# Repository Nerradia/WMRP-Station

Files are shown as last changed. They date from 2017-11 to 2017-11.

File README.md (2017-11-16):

# WMRP-Station

Seeing the quality of WMRP tips from Weller, I wanted to buil my own station, cheaper that the official one.
It is still in development and some improvements are still to be made.
There is two PCBs : The first one seats in the base, and the other one is in the handle.

The first circuit has two microcontrollers, one dedicated to power regulation, and the other one for everything else. The power regulation is made with a half-bridge filtered with two LC low-pass filters. The PWM frequency is at about 100 KHz (I'm not sure, I need to check that), this way, the heating element will receive a smooth current and voltage. On an early version of this station, which was sending square-waves, it seemed to break the heating element.

The second is just made of some sensors to measure temperature of the tip, measure the acceleration of the handle (for automatic start and stop), to detect touch and finally to light up an RGB LED. These two last functions are not yet implemented, I neeed to make an other PCB.

To order the last version of PCBs :
https://pcbs.io/share/zjX5Z
https://pcbs.io/share/z5bD1

BOM is coming soon.

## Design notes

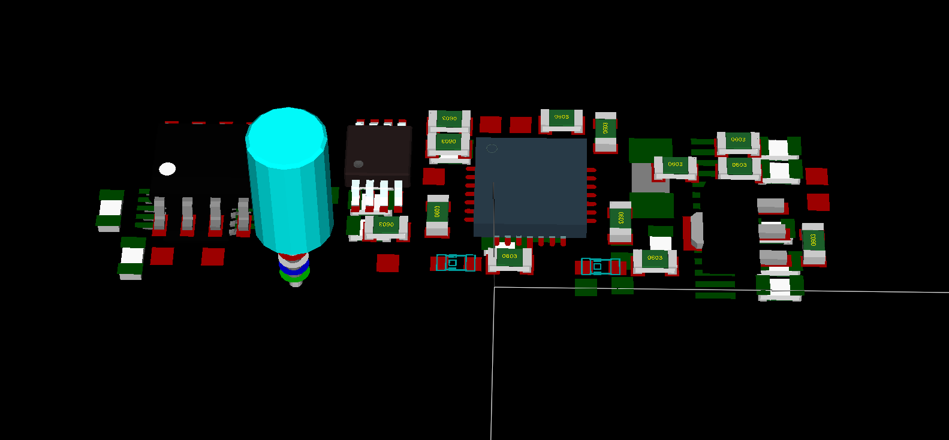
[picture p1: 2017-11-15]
handle/fer_a_souder.png

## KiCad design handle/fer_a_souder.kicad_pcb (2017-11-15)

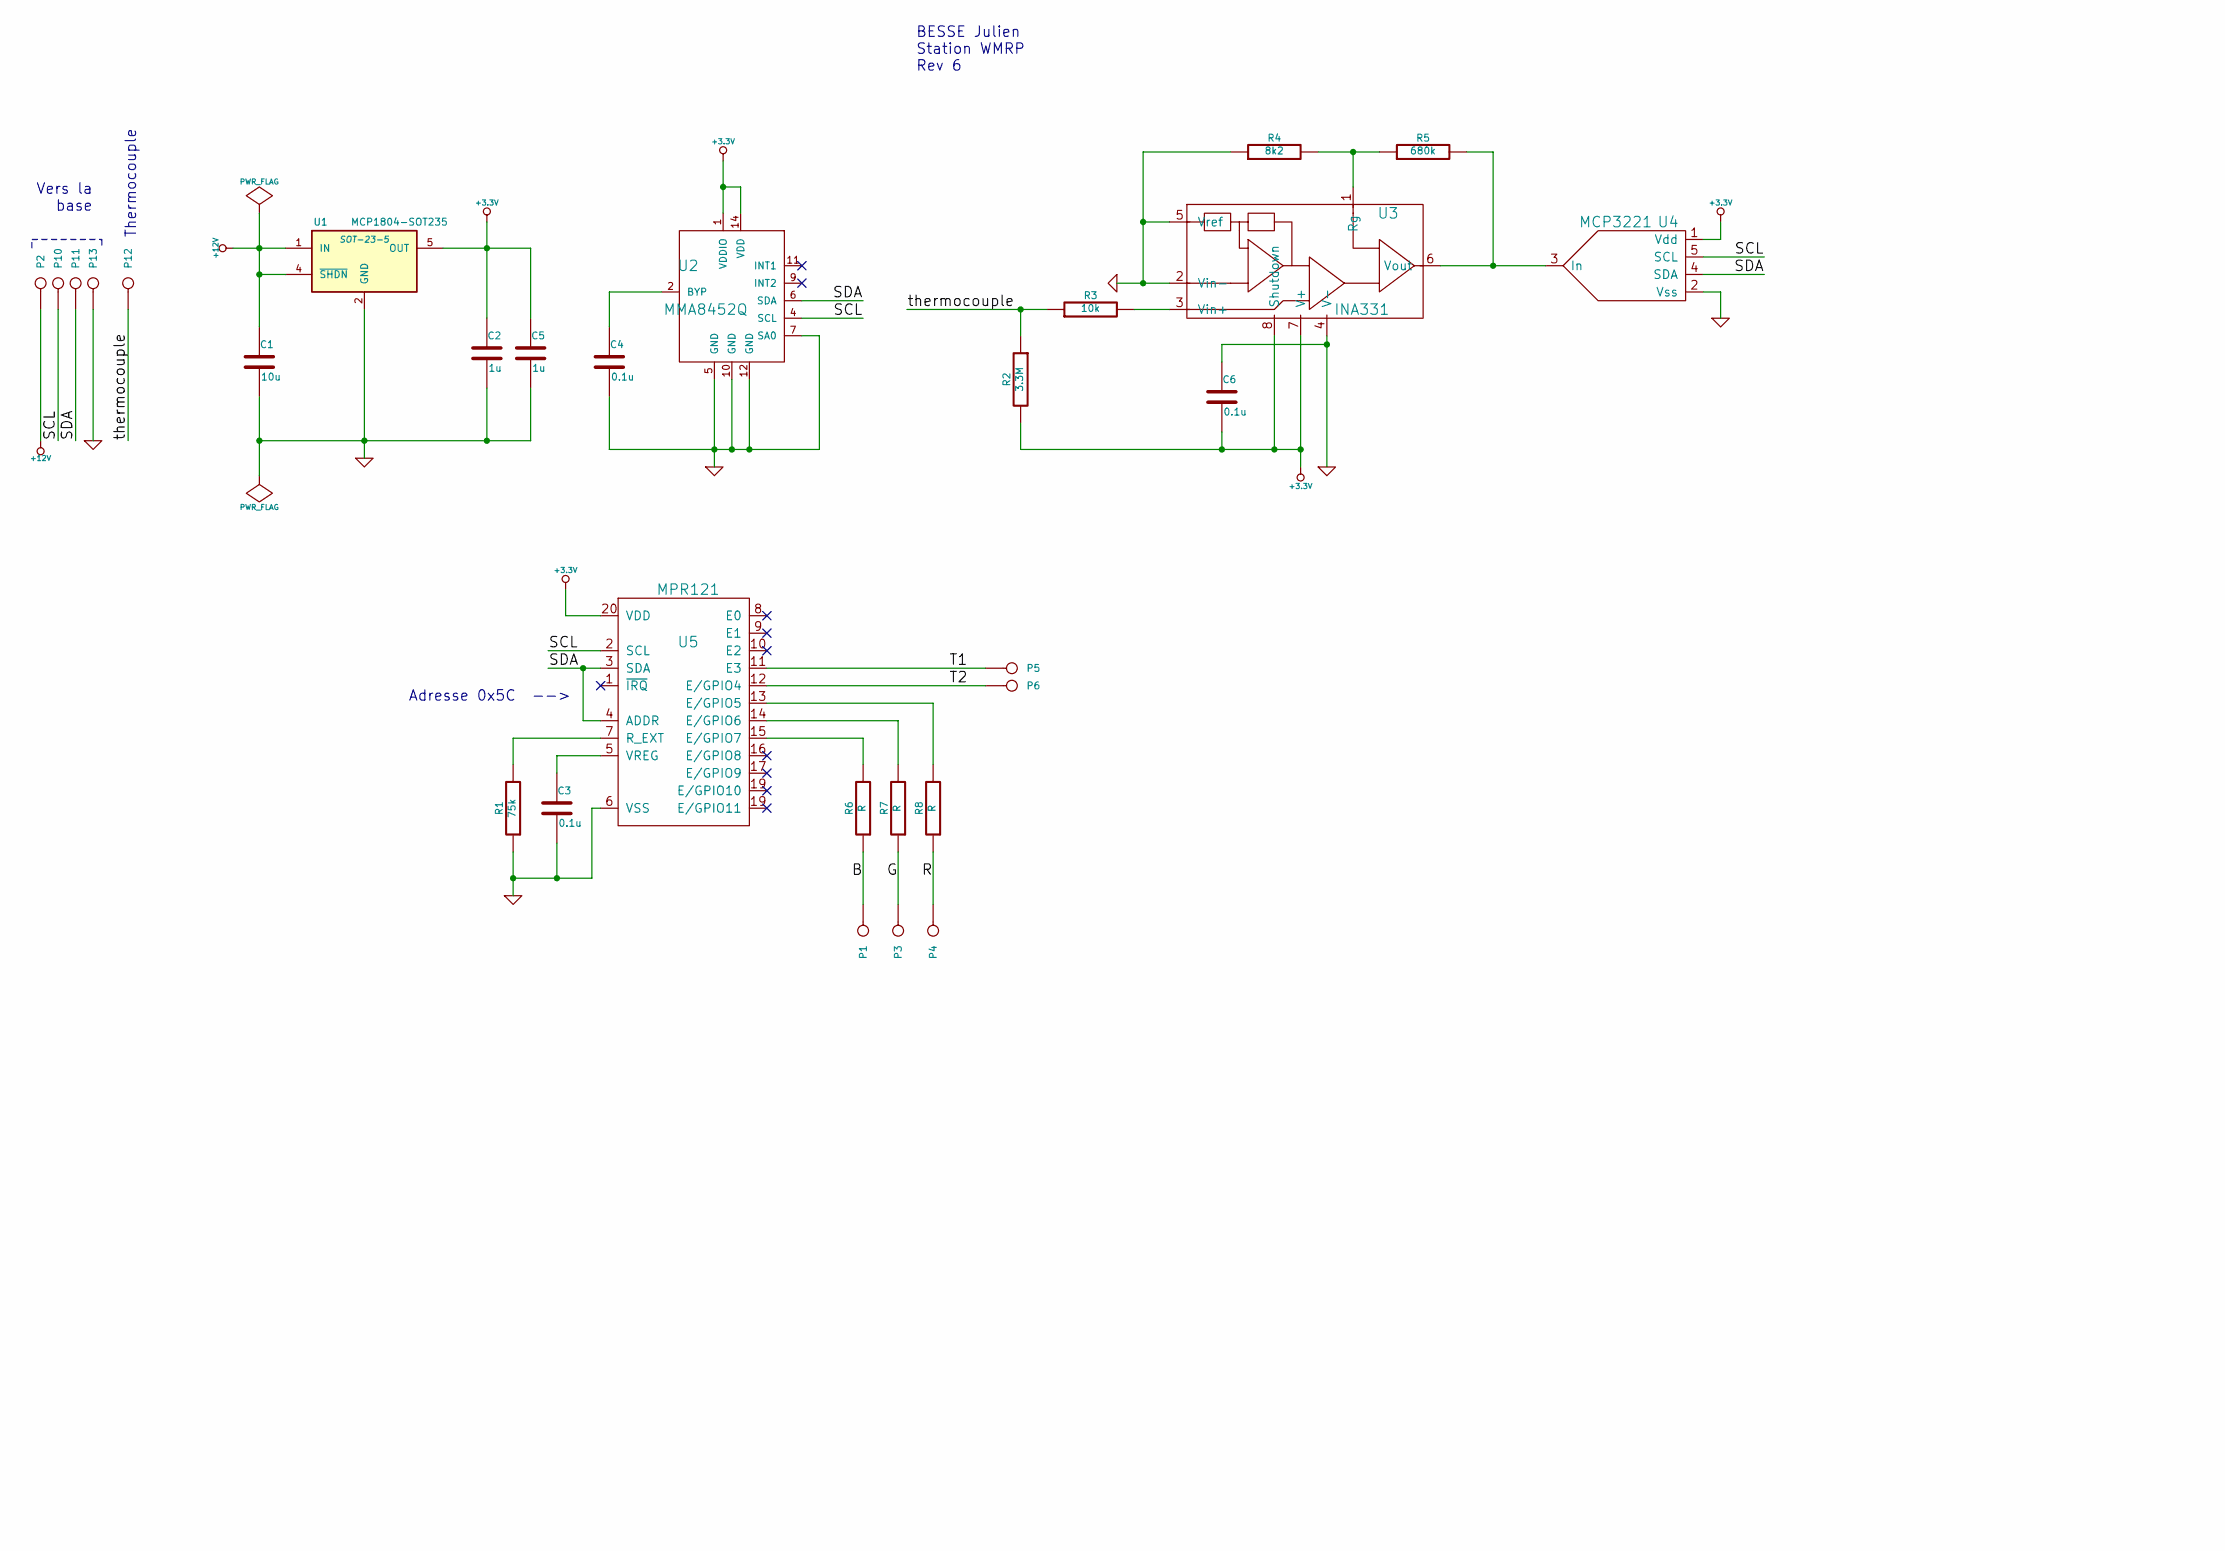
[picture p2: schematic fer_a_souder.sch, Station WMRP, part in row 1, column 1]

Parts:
C1: 10u
C2, C5: 1u
C3, C4, C6: 0.1u
P1, P2, P3, P4, P5, P6, P10, P11, P12, P13: CONN_1
R1: 75k
R2: 3.3M
R3: 10k
R4: 8k2
R5: 680k
R6, R7, R8: R
U1: MCP1804-SOT235; SOT-23-5
U2: MMA8452Q
U3: INA331
U4: MCP3221
U5: MPR121

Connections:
+3.3V: C2.1, C5.1, C6.2, R2.2, U1.5 (OUT), U2.1 (VDDIO), U2.14 (VDD), U3.7 (V+), U3.8 (Shutdown), U4.1 (Vdd), U5.20 (VDD)
+12V: C1.1, P2.1, U1.1 (IN), U1.4 (~SHDN)
/B: P1.1, R6.1
/G: P3.1, R7.1
/R: P4.1, R8.1
/SCL: P10.1, U2.4 (SCL), U4.5 (SCL), U5.2 (SCL)
/SDA: P11.1, U2.6 (SDA), U4.4 (SDA), U5.3 (SDA), U5.4 (ADDR)
/T1: P5.1, U5.11 (E3)
/T2: P6.1, U5.12 (E/GPIO4)
/thermocouple: P12.1, R2.1, R3.1
GND: C1.2, C2.2, C3.2, C4.2, C5.2, C6.1, P13.1, R1.1, R4.1, U1.2 (GND), U2.5 (GND), U2.7 (SA0), U2.10 (GND), U2.12 (GND), U3.2 (Vin-), U3.4 (V-), U3.5 (Vref), U4.2 (Vss), U5.6 (VSS)
unnamed: R1.2, U5.7 (R_EXT)
unnamed: C3.1, U5.5 (VREG)
unnamed: R8.2, U5.13 (E/GPIO5)
unnamed: R7.2, U5.14 (E/GPIO6)
unnamed: R6.2, U5.15 (E/GPIO7)
unnamed: C4.1, U2.2 (BYP)
unnamed: R4.2, R5.1, U3.1 (Rg)
unnamed: R3.2, U3.3 (Vin+)
unnamed: R5.2, U3.6 (Vout), U4.3 (In)

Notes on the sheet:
BESSE Julien Station WMRP Rev 6
Vers la base
Thermocouple
Adresse 0x5C -->

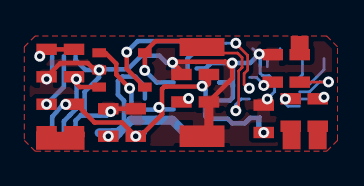
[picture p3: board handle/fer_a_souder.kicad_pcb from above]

Board: 2 copper layers, 29 parts (0 on the bottom side), 20 nets.

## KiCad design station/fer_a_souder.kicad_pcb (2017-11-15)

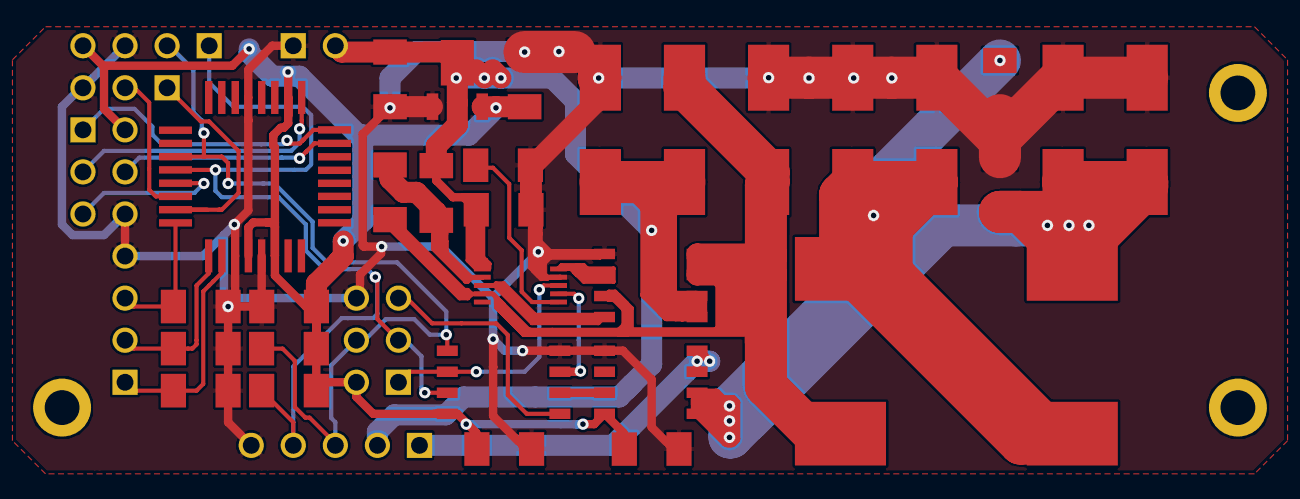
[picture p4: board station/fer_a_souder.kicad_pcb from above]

Board: 2 copper layers, 42 parts (0 on the bottom side), 26 nets.

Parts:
C1, C2, C3, C6, C7, C12, C15, C17: 1u; SM1206
C4: CAPAPOL; SMD2917
C5, C8, C16, C18: 100u; SMD2917
C10, C13, C14: 1n; SM1206
C11: 200n; SM1206
CON1, CON2: AVR-ISP-6; pin_array_3x2
D1, D2: DIODESCH; SMD2917
D5: DIODE; SM1206
IC1: ATMEGA328P-A; TQFP32
IC2: ATTINY85-S; SOIC-8
K1: CONN_3; PIN_ARRAY_3X1
L1, L2: 47u; INDCMS12.5
P1: CONN_2; PIN_ARRAY_2X1
P2: CONN_5; PIN_ARRAY_5x1
P3, P4: CONN_4; PIN_ARRAY_4x1
R1: 10k; SM1206
R2, R3: 2.2k; SM1206
TrouFixation2.1mm, TrouFixation2.1mm#2, TrouFixation2.1mm#3: P***; trouFixation3.1mm
U1: 7805; sot89
U2: LM5106; msoic-10
U3: ACS712; so-8
U5: FDS6898A; so-8
svg2mod-rev: G***; svg2mod-rev

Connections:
+3.3V: C1.1, C3.1, C6.2, C7.1, CON1.2, CON2.2, IC1.4, IC1.6, IC1.18, IC2.8, P3.4, R2.1, R3.1, U1.VO, U3.8
+12V: C2.1, C4.1, C12.1, D1.1, D5.1, P1.2, P2.2, U1.VI, U2.1, U5.5, U5.6
/ISENS: IC2.2, U3.7
/MISO: CON1.1, IC1.16
/MISO2: CON2.1, IC2.6, U2.8
/MOSI: CON1.4, IC1.15
/MOSI2: CON2.4, IC1.27, IC2.5, P2.3, P3.2, R2.2
/RST: CON1.5, IC1.29
/RST_2: CON2.5, IC2.1
/RXD: IC1.30, K1.2
/SCK: CON1.3, IC1.17
/SCK_2: CON2.3, IC1.28, IC2.7, P2.4, P3.1, R3.2
/TXD: IC1.31, K1.1
/p: C10.1, IC1.2, P4.1
/pont_en: IC2.3, U2.7
/r+: C14.1, IC1.32, P4.3
/r-: C13.1, IC1.1, P4.2
/resistance: P2.1, U3.3, U3.4
GND: C1.2, C2.2, C3.2, C4.2, C5.2, C6.1, C7.2, C8.2, C10.2, C12.2, C13.2, C14.2, C15.2, C16.2, C17.2, C18.2, CON1.6, CON2.6, D2.2, IC1.3, IC1.5, IC1.21, IC2.4, K1.3, P1.1, P2.5, P3.3, P4.4, R1.2, U1.GND, U2.9, U3.5, U5.1
unnamed: C11.1, D5.2, U2.2
unnamed: R1.1, U2.6
unnamed: U2.3, U5.4
unnamed: U2.10, U5.2
unnamed: C11.2, D1.2, D2.1, L1.1, U2.4, U5.3, U5.7, U5.8
unnamed: C8.1, C17.1, C18.1, L2.2, U3.1, U3.2
unnamed: C5.1, C15.1, C16.1, L1.2, L2.1

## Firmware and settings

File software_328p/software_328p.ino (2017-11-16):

/* ************************
	Julien BESSE
	https://julienbesse.fr

	First sketch for the soldering station.

	Compile it for "Arduino breadboard 8 MHz" :
		Go to https://www.arduino.cc/en/Tutorial/ArduinoToBreadboard,
		Then read "Minimal Circuit"

	Upload it to the microcontroller with an ISP programmer

This software is VERY UGLY as I just made a sketch to test the hardware. I need to clean it and use english instead of french.

*/

/*********************************************************************
This example is for a 128x64 size display using I2C to communicate
3 pins are required to interface (2 I2C and one reset)

Adafruit invests time and resources providing this open source code, 
please support Adafruit and open-source hardware by purchasing 
products from Adafruit!

Written by Limor Fried/Ladyada  for Adafruit Industries.  
BSD license, check license.txt for more information
All text above, and the splash screen must be included in any redistribution
*********************************************************************/
#include <EEPROM.h>
#include <SPI.h>
#include <Wire.h>
#include <Adafruit_GFX.h>
#include <Adafruit_SSD1306.h>
#include <SparkFun_MMA8452Q.h>
#include <Adafruit_MLX90614.h>
#include "Adafruit_MPR121.h"
#include <avr/wdt.h>

#define OLED_RESET 7
Adafruit_SSD1306 display(OLED_RESET);

#define NUMFLAKES 10
#define XPOS 0
#define YPOS 1
#define DELTAY 2

#define pin_n 3
#define pin_p 2
#define pin_bp 4

MMA8452Q accel;
Adafruit_MLX90614 mlx = Adafruit_MLX90614();

Adafruit_MPR121 cap = Adafruit_MPR121();

uint16_t TemperatureCible = 300;
uint16_t acc;
uint8_t capteurIR = 0; // Booléen indiquant la présence d'un capteur GY-906
uint8_t MPR = 0; // Pareil pour capteur tacile et LED

#define LOGO_H 49 
#define LOGO_W  72
const unsigned char logo [] PROGMEM = {
  // 'g4798'
  0x00, 0x00, 0x00, 0x00, 0x00, 0x00, 0x00, 0x00, 0x00, 0x00, 0x00, 0x00, 0x00, 0x00, 0x00, 0x00, 
  0x00, 0x06, 0x00, 0x00, 0x00, 0x00, 0x00, 0x00, 0x00, 0x00, 0x1c, 0x00, 0x00, 0x00, 0x00, 0x00, 
  0x00, 0x00, 0x00, 0x38, 0x00, 0x00, 0x00, 0x00, 0x00, 0x00, 0x00, 0x00, 0xf0, 0x00, 0x00, 0x00, 
  0x00, 0x00, 0x00, 0x00, 0x03, 0xe0, 0x00, 0x00, 0x00, 0x00, 0x00, 0x00, 0x00, 0x07, 0xc0, 0x00, 
  0x00, 0x00, 0x00, 0x00, 0x00, 0x00, 0x1f, 0x00, 0x00, 0x00, 0x00, 0x00, 0x00, 0x00, 0x00, 0x7e, 
  0x00, 0x00, 0x00, 0x00, 0x00, 0x00, 0x00, 0x00, 0xfc, 0x00, 0x00, 0x00, 0x00, 0x00, 0x00, 0x00, 
  0x13, 0xf0, 0x00, 0x00, 0x00, 0x00, 0x00, 0x00, 0x00, 0x6f, 0xe0, 0x00, 0x00, 0x00, 0x00, 0x00, 
  0x00, 0x00, 0xdf, 0x80, 0x00, 0x00, 0x00, 0x00, 0x00, 0x00, 0x03, 0xff, 0x00, 0x00, 0x00, 0x00, 
  0x00, 0x00, 0x00, 0x07, 0xfc, 0x00, 0x00, 0x00, 0x00, 0x00, 0x00, 0x00, 0x1f, 0xf8, 0x00, 0x06, 
  0x00, 0x00, 0x00, 0x00, 0x40, 0x3f, 0xe0, 0x00, 0x3c, 0x00, 0x00, 0x00, 0x00, 0x40, 0x7f, 0xc0, 
  0x00, 0xf8, 0x00, 0x00, 0x00, 0x00, 0xc1, 0xff, 0x00, 0x07, 0xe0, 0x00, 0x00, 0x00, 0x01, 0x83, 
  0xfe, 0x00, 0x1f, 0xc0, 0x00, 0x00, 0x00, 0x03, 0x9f, 0xf8, 0x00, 0xff, 0x00, 0x00, 0x00, 0x00, 
  0x03, 0x3f, 0xf0, 0x37, 0xf8, 0x00, 0x1f, 0xf0, 0x7f, 0xff, 0xff, 0xc3, 0xff, 0xe0, 0x00, 0x1f, 
  0xf0, 0x7f, 0xff, 0xff, 0x9f, 0xff, 0x80, 0x00, 0x1f, 0xf0, 0x7f, 0xff, 0xfe, 0xff, 0xfc, 0x00, 
  0x00, 0x01, 0xf0, 0x7c, 0x3f, 0xff, 0xff, 0xe0, 0x00, 0x00, 0x01, 0xf0, 0x7c, 0x1f, 0xff, 0xff, 
  0x00, 0x00, 0x00, 0x01, 0xf0, 0x7c, 0x1f, 0xff, 0xfc, 0x00, 0x00, 0x00, 0x01, 0xf0, 0x7c, 0x1f, 
  0xff, 0xe0, 0x00, 0x00, 0x1c, 0x01, 0xf0, 0x7f, 0xff, 0xff, 0x00, 0x00, 0x1f, 0xf8, 0x01, 0xf0, 
  0x7f, 0xff, 0xf0, 0xff, 0xbf, 0xff, 0xc0, 0x01, 0xf0, 0x7f, 0xff, 0xff, 0xff, 0xff, 0xfc, 0x00, 
  0x01, 0xf0, 0x7f, 0xff, 0xff, 0xff, 0xff, 0xc0, 0x00, 0x01, 0xf0, 0x7c, 0x0f, 0xff, 0xff, 0xf0, 
  0x00, 0x00, 0x01, 0xf0, 0x7c, 0x07, 0xff, 0xfc, 0x00, 0x00, 0x00, 0x01, 0xf0, 0x7c, 0x07, 0xfc, 
  0x00, 0x00, 0x00, 0x00, 0x01, 0xf0, 0x7c, 0x0f, 0xff, 0x80, 0x00, 0x00, 0x00, 0x83, 0xf0, 0x7c, 
  0x1f, 0xff, 0xfc, 0x00, 0x00, 0x00, 0xff, 0xf0, 0x7f, 0xff, 0xff, 0xfe, 0x00, 0x00, 0x00, 0xff, 
  0xe0, 0x7f, 0xff, 0xff, 0xff, 0xff, 0x00, 0x00, 0xff, 0xc0, 0x7f, 0xff, 0xc7, 0xff, 0xff, 0xfe, 
  0x00, 0x7f, 0x00, 0x00, 0x1f, 0xf8, 0x01, 0xff, 0xfe, 0x00, 0x00, 0x00, 0x00, 0x03, 0xfe, 0x00, 
  0x00, 0x00, 0x00, 0x00, 0x00, 0x00, 0x00, 0xff, 0x80, 0x00, 0x00, 0x00, 0x00, 0x00, 0x00, 0x00, 
  0x1f, 0xe0, 0x00, 0x00, 0x00, 0x00, 0x00, 0x00, 0x00, 0x03, 0xf0, 0x00, 0x00, 0x00, 0x00, 0x00, 
  0x00, 0x00, 0x00, 0x7e, 0x00, 0x00, 0x00, 0x00, 0x00, 0x00, 0x00, 0x00, 0x07, 0xc0, 0x00, 0x00, 
  0x00, 0x00, 0x00, 0x00, 0x00, 0x00, 0x70, 0x00, 0x00
};

#if (SSD1306_LCDHEIGHT != 64)
#error("Height incorrect, please fix Adafruit_SSD1306.h!");
#endif

int16_t setHeatgetCurrent(uint8_t n, uint8_t puissance) {
  Wire.beginTransmission(0x18);
  Wire.write(n);
  Wire.write(puissance);
  Wire.endTransmission();
  Wire.requestFrom(0x18, 2);
  return ((Wire.read() << 8 | Wire.read()) - 517) * 3.22265625 / 0.110 / 1.1384615384615384615384615384615;
 //return Wire.read() << 8 | Wire.read();
}

uint16_t getTemp() {
  do {
  Wire.beginTransmission(0x4D);
  } while (Wire.endTransmission());
  Wire.requestFrom(0x4D, 2);
  return 0.1224 / 1.1515 * (Wire.read() << 8 | Wire.read()) + 96;
}

uint16_t getAcc() {
  static int16_t ax, ay, az, dx, dy, dz, ds;
  accel.read();
  dx = accel.x - ax;
  dy = accel.y - ay;
  dz = accel.z - az;
  ax = accel.x;
  ay = accel.y;
  az = accel.z;
  return (uint16_t)sqrt(pow(dx,2)+pow(dy,2)+pow(dz,2));
}

// Fonction appelée lors d'une interruption déclenchée par un changement d'état sur un des pins du bouton rotatif
void Encodeur() {
  if(digitalRead(pin_n)==HIGH){
    if (TemperatureCible <= 410) {
      TemperatureCible += 10;
    }
  }else {
    if (TemperatureCible >= 210) {
      TemperatureCible -= 10;
    }
  }
}

#define debug_x 2
#define debug_y 1
#define debug_ok_y 110

void setup() { 
  wdt_disable();
  wdt_enable(WDTO_1S);
  pinMode(pin_n, INPUT_PULLUP);
  pinMode(pin_p, INPUT_PULLUP);
  pinMode(pin_bp, INPUT_PULLUP);
  wdt_reset();
  delay(500);
  display.begin(SSD1306_SWITCHCAPVCC, 0x3C);
  display.display();
  display.fillScreen(BLACK);
  display.setTextSize(1);
  display.setTextColor(WHITE);
  display.setCursor(debug_x, debug_y);
  delay(1);
  wdt_reset();

  display.drawBitmap(128/2-LOGO_W/2, 64-LOGO_H, logo, LOGO_W, LOGO_H, WHITE);
  display.display();

  display.print("Attiny85...");
  display.display();
  do {
  Wire.beginTransmission(0x18); // Tentative de connexion à l'attiny85
  } while (Wire.endTransmission());
  display.fillRect(0, 0, 128, 20, BLACK);
  wdt_reset();
  
  display.setCursor(debug_x, debug_y);
  display.print("ADC...");
  display.display();
  do {
  Wire.beginTransmission(0x4D);
  } while (Wire.endTransmission());
  display.fillRect(0, 0, 128, 20, BLACK);
  wdt_reset();
  
  display.setCursor(debug_x, debug_y);
  display.print("Accelerometre...");
  display.display();
  do {
  Wire.beginTransmission(0x1C);
  } while (Wire.endTransmission());
  display.fillRect(0, 0, 128, 20, BLACK);
  accel.init(SCALE_2G, ODR_50);
  //getAcc();
  acc = getAcc();
  wdt_reset();

  display.setCursor(debug_x, debug_y);
  display.print("EEPROM...");
  display.display();
  TemperatureCible = EEPROM.read(0x00) | EEPROM.read(0x01) << 8 | EEPROM.read(0x02) << 16 | EEPROM.read(0x03) << 24;
    if (TemperatureCible > 420 || TemperatureCible < 200) {
    TemperatureCible = 320;
  }
  display.fillRect(0, 0, 128, 20, BLACK);
  wdt_reset();
  
  display.setCursor(debug_x, debug_y);
  display.print("Capteur IR...");
  display.display();
  Wire.beginTransmission(0x5A);
  int retourIR = Wire.endTransmission();

  if (retourIR == 0) {
    capteurIR = 1;
  } else {
    capteurIR = 0;
  } 
  display.display();
  display.fillRect(0, 0, 128, 20, BLACK);
  wdt_reset();
  
  display.setCursor(debug_x, debug_y);
  display.print("Tactile/LED...");
  display.display();

  if (cap.begin(0x5C)) {
    MPR = 1;
  } else {
    MPR = 0;
  } 
  display.fillRect(0, 0, 128, 20, BLACK);
  wdt_reset();
  attachInterrupt(digitalPinToInterrupt(pin_p), Encodeur, RISING); // L'interruption pour le bouton rotatif
}



void loop() {
  wdt_reset();
  if (accel.available())
  {
    acc = getAcc();
  }

  

  Wire.beginTransmission(0x5A);
  int retourIR = Wire.endTransmission();
  if (retourIR == 0) {
    capteurIR = 1;
  } else {
    capteurIR = 0;
  }

  static char etatPrecedent = 0;
  static char  on = 0;
  if (acc > 500 || acc > 50 && etatPrecedent) on = 30;
  if (on > 0) etatPrecedent = on--;

  if (digitalRead(pin_bp)){
    EEPROM.write(0x00, TemperatureCible & 0xFF);
    EEPROM.write(0x01, (TemperatureCible << 8) & 0xFF);
    EEPROM.write(0x02, (TemperatureCible << 16)  & 0xFF);
    EEPROM.write(0x03, (TemperatureCible << 24)  & 0xFF);
  }

  int16_t courant = setHeatgetCurrent(0, 0);
  static int16_t courantLisse = 0;
   courantLisse = (courantLisse + courant) / 2;
  delay(1); // On attend un peu avant de mesurer la température
  
  uint16_t Temperature = getTemp();
  static uint16_t TemperatureLisse = 0;
  TemperatureLisse = (TemperatureLisse * 2 + Temperature) / 3;

  uint8_t nchauffage = 0;

  if (Temperature > TemperatureCible) nchauffage = 0;
  else  if (on) {
    uint16_t diff = TemperatureCible - Temperature;
    if (diff < 5) nchauffage = 5;
    else if (diff < 20) nchauffage = 40;
    else nchauffage = 80; 
  }

  const uint16_t puissanceCible = 40000;
  static uint8_t valPWM = 100;
  uint32_t puissance = (uint16_t) courant * (12 * valPWM / 255.);
  if (puissance > puissanceCible + 10000) {
    valPWM = (valPWM > 50) ? valPWM - 15 : 0;
  } else if (puissance > puissanceCible + 5000) {
    valPWM = (valPWM > 20) ? valPWM - 2 : 0;
  } else if (puissance > puissanceCible + 2000) {
    valPWM = (valPWM > 1) ? valPWM - 1 : 0;
  } else if (puissance < puissanceCible - 2000) {
    valPWM = (valPWM < 255 - 50) ? valPWM + 15 : 255;
  } else if (puissance < puissanceCible - 5000) {
    valPWM = (valPWM < 255 - 20) ? valPWM + 2 : 255;
  } else if (puissance < puissanceCible - 10000) {
    valPWM = (valPWM < 255 - 1) ? valPWM + 1 : 255;
  }
  
  if (on) setHeatgetCurrent(nchauffage, valPWM); //

  display.fillScreen(BLACK);

  if(capteurIR) {
    display.setTextSize(3);
    display.setCursor(2,22);
    if (Temperature >= 120 && Temperature < 529) {
      display.print(TemperatureLisse);  // On affiche la température si elle est supérieure à 100°CLisse
      display.setTextSize(2);
      display.print("C");
    }
    else {
      display.print("---");
    }
    display.setTextSize(2);
    display.setCursor(88,15);
    display.print(mlx.readObjectTempC(),0);
    display.setTextSize(1);
    display.print("C");
    display.setTextSize(2);
    display.setCursor(88,31);
    display.print(mlx.readAmbientTempC(),0);
    display.setTextSize(1);
    display.print("C");
    
  } else {
    display.setTextSize(4);
    display.setCursor(2,22);
    if (Temperature >= 120 && Temperature < 529) {
      display.print(TemperatureLisse);  // On affiche la température si elle est supérieure à 100°CLisse
    }
    else {
      display.print("---");
    }
    display.setCursor(85,18);
    display.setTextSize(2);
    display.print("o");
    display.setCursor(100,18);
    display.setTextSize(3);
    display.print("C");
  }
  display.setTextSize(2);
  display.setCursor(1,1);
  char TemperatureCibleAffichage[6];
  sprintf(TemperatureCibleAffichage, "%3d", TemperatureCible);
  display.print(TemperatureCibleAffichage);
  display.setTextSize(1);
  display.print("C");


  char enHautADroite2[10];
  display.drawFastHLine(55, 0, sqrt(acc), WHITE); 
  display.setTextSize(1);
  if ( Temperature < 529) {
    sprintf(enHautADroite2, "%ld", puissance);
  } else {
    sprintf(enHautADroite2, "-.--");
  }
  display.setCursor(93,4);
  display.print(enHautADroite2);
  display.setCursor(55, 4);
  char enHautADroite1[10];
  if (on)
  sprintf(enHautADroite1, "ON %2d", on);
  else
  sprintf(enHautADroite1, "OFF");

  display.print(enHautADroite1);

  if ( Temperature < 529) {
    display.fillRect(0,57 , (TemperatureLisse>80) ? (TemperatureLisse-60)*128./370 : 1, 6, WHITE);
    display.fillTriangle( (TemperatureCible-60)*128./370. - 2 , 50, (TemperatureCible-60)*128./370., 55, (TemperatureCible-60)*128./370. +2, 50, WHITE);
  }
/*
  if(MPR) {
    display.setCursor(1, 55);
    display.print(cap.touched(), BIN);
    
  }
    */
  display.display();
  display.fillScreen(BLACK);
  display.setCursor(1,1);
}

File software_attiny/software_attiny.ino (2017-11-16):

/* 

  Julien BESSE

  Use board "Attiny 85" at 8 MHz :
  https://github.com/damellis/attiny/archive/master.zip

  Upload it to the microcontroller with an ISP programmer

*/


#include <TinyWireS.h>
//#include <usiTwiSlave.h>

// D4   : Pont_en
// A3 D3: Courant
// D2   : SCL
// D1   : Pont_in
// D0   : SDA

//Sine Wave Look Up Table 
const unsigned char demisinus[] = {
  0,   3,   6,   9,  12,  15,  18,  22,  25,  28,  31,  34,  37,  40,  43,  47,  50,  53,  56,  59,  62,  65,  68,  71,  74,  77,  80,  83,  86,  89,  92,  95,  98, 101, 104, 106, 109, 112, 115, 118, 121, 123, 126, 129, 132, 134, 137, 140, 142, 145, 147, 150, 152, 155, 157, 160, 162, 165, 167, 170, 172, 174, 176, 179, 181, 183, 185, 187, 190, 192, 194, 196, 198, 200, 202, 204, 205, 207, 209, 211, 213, 214, 216, 218, 219, 221, 222, 224, 225, 227, 228, 230, 231, 232, 234, 235, 236, 237, 238, 239, 240, 241, 242, 243, 244, 245, 246, 247, 247, 248, 249, 250, 250, 251, 251, 252, 252, 253, 253, 253, 254, 254, 254, 254, 254, 254, 254, 255, 254, 254, 254, 254, 254, 254, 254, 253, 253, 253, 252, 252, 251, 251, 250, 250, 249, 248, 247, 247, 246, 245, 244, 243, 242, 241, 240, 239, 238, 237, 236, 235, 234, 232, 231, 230, 228, 227, 225, 224, 222, 221, 219, 218, 216, 214, 213, 211, 209, 207, 205, 204, 202, 200, 198, 196, 194, 192, 190, 187, 185, 183, 181, 179, 176, 174, 172, 170, 167, 165, 162, 160, 157, 155, 152, 150, 147, 145, 142, 140, 137, 134, 132, 129, 126, 123, 121, 118, 115, 112, 109, 106, 104, 101,  98,  95,  92,  89,  86,  83,  80,  77,  74,  71,  68,  65,  62,  59,  56,  53,  50,  47,  43,  40,  37,  34,  31,  28,  25,  22,  18,  15,  12,   9,   6,   3,   0,
};

uint16_t courant_cible = 0;

void setup() {
  pinMode(4, OUTPUT);
  pinMode(1, OUTPUT);
  digitalWrite(1, LOW);

  TinyWireS.begin(24);  // Activation de l'I2C avec l'adresse 24, soit Ox18.

  // Activation de la PLL 64 Mhz
  PLLCSR |= (1 << PLLE);
  delayMicroseconds(100);
  while(!(PLLCSR & (1 << PLOCK)));  // On attend qu'elle se verrouille

  // Config des registres PWM pour sortie sur OC1B (pin 3, port 4)
  PLLCSR |= (1<<PCKE);
  TCCR1 = (0 << PWM1A) | (0 << COM1A0) | (1 << CS10) | (1 << CS11);
  GTCCR = (1 << PWM1B) | (1 << COM1B1);

}

unsigned int pic_courant = 0;
unsigned int n_impulsions = 0;
float puissance = 0.1;

void loop() {
 // while(n_impulsions > 0) {
    if (n_impulsions > 0) {
      digitalWrite(1, HIGH);
      TCCR1 = (0 << PWM1A) | (0 << COM1A0) | (1 << CS10) | (1 << CS11);
      for(int i = 0; i < 255; i++) {
        OCR1B = (uint8_t) demisinus[i] * puissance;
        if (i == 127) {
          pic_courant = analogRead(A3);
          delay(n_impulsions);
        }
      }
      digitalWrite(1, LOW);
      TCCR1 = 0;
  
      n_impulsions = 0;
    }
  //  n_impulsions--;
 // }
  
  if (TinyWireS.available()){          
    n_impulsions = TinyWireS.receive();
    puissance    = TinyWireS.receive() / 255.;
    TinyWireS.send(pic_courant >> 8);
    TinyWireS.send(pic_courant & 0xFF);

    if (n_impulsions > 80) n_impulsions = 0;
    if (puissance > 1) n_impulsions = 0;
  }
}

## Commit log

2017-11-15 Initial commit
    There's a bad component in cache (the power MOSFET)
    [fer_a_souder.kicad_pcb, fer_a_souder.sch]
2017-11-15 Initial commit, I have to check it
    [fer_a_souder.kicad_pcb, fer_a_souder.sch]
2017-11-16 Swapped folders
    [fer_a_souder.kicad_pcb, fer_a_souder.sch]
